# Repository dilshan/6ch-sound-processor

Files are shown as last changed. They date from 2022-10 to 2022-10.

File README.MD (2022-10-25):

# 5.1 channel analog audio processor

This project is a 5.1-channel, analog audio processor based on *PT2322* and [Arduino Nano](https://store.arduino.cc/products/arduino-nano).

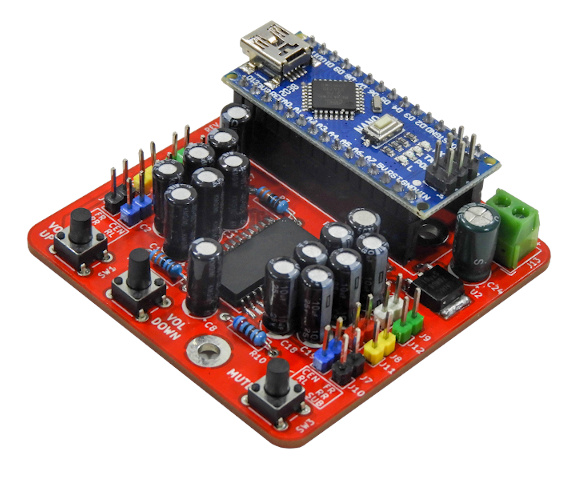
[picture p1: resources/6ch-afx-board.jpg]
Finished 5.1-channel analog audio processor board.


[*PT2322*](https://www.alldatasheet.com/datasheet-pdf/pdf/167269/ETC1/PT2322.html) is an inexpensive analog audio processor introduced by [*Princeton Technology Corporation*](http://www.princeton.com.tw/). It contains 6-channel individual channel attenuators, a 3-way tone control system for front-end speakers, and a 3D audio simulation system.

In this design, we combine *PT2322* with *Arduino Nano* and interface it with PC/embedded computing boards through a USB port. Native *GTK* UI application provides to control all functions of the *PT2322* IC.

This audio processing module is an open-source hardware project. All the design files, source codes, and compiled binaries are available in this repository.

- [6ch-sound-fx-arduino](https://github.com/dilshan/6ch-sound-processor/tree/main/6ch-sound-fx-arduino): Source code of the *Arduino Nano* firmware.
- [6ch-sound-fx-controller](https://github.com/dilshan/6ch-sound-processor/tree/main/6ch-sound-fx-controller): Source code of the sound processor control application.
- [kicad-design](https://github.com/dilshan/6ch-sound-processor/tree/main/kicad-design): *KiCAD* 6 schematic and PCB design.

## Assembling the module

The PCB of this module can directly order from the [PCBWay project page](https://www.pcbway.com/project/shareproject/5_1_channel_analog_audio_processor_231ad745.html). Also, the latest Gerber files of this module are available in the [release](https://github.com/dilshan/6ch-sound-processor/releases) section of this repository.

All the required components to assemble this module are in the BOM file at [here](https://github.com/dilshan/6ch-sound-processor/tree/main/kicad-design/6ch-sound-fx-proc-bom.pdf).

The entire assembly process of this module is shown in the below video:

5.1 Channel Audio Processor (https://youtu.be/wblaniLDYwU)

## Compiling source codes

*Arduino Nano* firmware of this project is written using [*PlatformIO*](https://platformio.org/). To compile and install the firmware, use the latest version of [*PlatformIO IDE*](https://platformio.org/platformio-ide).

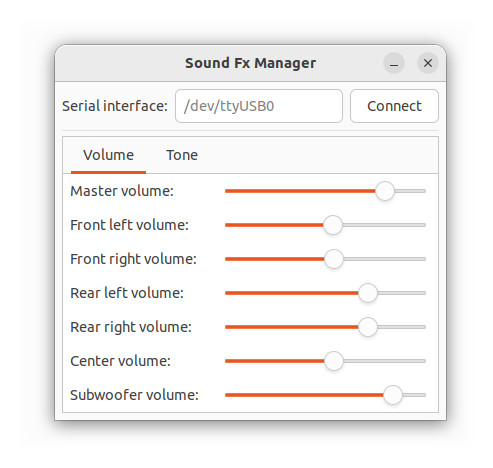
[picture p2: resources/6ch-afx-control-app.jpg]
Sound processor control application


The sound processor control application is a *GTK* application. *GTK* 3 development packages are required to compile this application. To compile the application, issue the `make` command from the source directory.

```
$ git clone git@github.com:dilshan/6ch-sound-processor.git
$ cd 6ch-sound-processor/6ch-sound-fx-controller/
$ make
```

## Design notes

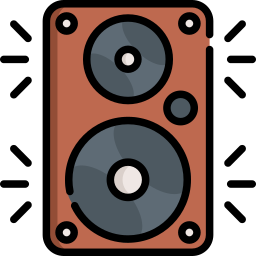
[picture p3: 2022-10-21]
6ch-sound-fx-controller/6ch-tone-control.png

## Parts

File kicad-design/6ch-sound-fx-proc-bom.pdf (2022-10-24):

6ch-sound-fx-proc

Reference(s) | Value | Footprint
A1 | Arduino Nano (V3) | Arduino Nano
| 10MFD / 16V | THT (Electrolytic capacitor)
C7,C9 | 0.0022MFD | SMD (0805)
C10,C11,C12,C13 | 0.01MFD | SMD (0805)
C14,C15,C16,C17,C26 | 0.1MFD | SMD (0805)
C24 | 100MFD / 16V | THT (Electrolytic capacitor)
C25 | 22MFD / 16V | THT (Electrolytic capacitor)
| 2.54mm 2-pin | 2.54mm, 2-pin male header
J13 | 2.54mm 2-pin | 2.54mm, 2-pin terminal block
Q1,Q2 | 2N7002 | SOT-23
| 100K | SMD (0805)
R7,R8 | 3.3K | THT (1% Metal film resistor)
R9,R10 | 6.2K | THT (1% Metal film resistor)
R17,R18,R19,R20 | 10K | SMD (0805)
R21 | 0R | SMD (0805)
SW1,SW2,SW3 | 6mm Tactile Switch
U1 | PT2322 | SSOP-28
U2 | LM78M08 | TO-252-2

C1,C2,C3,C4,C5,C6,C8,C18,C19,C 20,C21,C22,C23,C27

J1,J2,J3,J4,J5,J6,J7,J8,J9,J10,J11, J12

R1,R2,R3,R4,R5,R6,R11,R12,R13, R14,R15,R16

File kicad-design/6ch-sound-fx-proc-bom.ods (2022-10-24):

Reference(s) | Value | Footprint
A1 | Arduino Nano (V3) | Arduino Nano
C1,C2,C3,C4,C5,C6,C8,C18,C19,C20,C21,C22,C23,C27 | 10MFD / 16V | THT (Electrolytic capacitor)
C7,C9 | 0.0022MFD | SMD (0805)
C10,C11,C12,C13 | 0.01MFD | SMD (0805)
C14,C15,C16,C17,C26 | 0.1MFD | SMD (0805)
C24 | 100MFD / 16V | THT (Electrolytic capacitor)
C25 | 22MFD / 16V | THT (Electrolytic capacitor)
J1,J2,J3,J4,J5,J6,J7,J8,J9,J10,J11,J12 | 2.54mm 2-pin | 2.54mm, 2-pin male header
J13 | 2.54mm 2-pin | 2.54mm, 2-pin terminal block
Q1,Q2 | 2N7002 | SOT-23
R1,R2,R3,R4,R5,R6,R11,R12,R13,R14,R15,R16 | 100K | SMD (0805)
R7,R8 | 3.3K | THT (1% Metal film resistor)
R9,R10 | 6.2K | THT (1% Metal film resistor)
R17,R18,R19,R20 | 10K | SMD (0805)
R21 | 0R | SMD (0805)
SW1,SW2,SW3 | 6mm Tactile Switch
U1 | PT2322 | SSOP-28
U2 | LM78M08 | TO-252-2

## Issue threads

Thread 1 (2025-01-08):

hey no issue here but have a question about this project

Rick20230, 2025-01-08:
Hi im new to Arduino and esp32 stuff is there a way to have a wireless rf remote with 2 decoders one for 4 channels volume control and another decoder for 2 channels volume control i dont need any eq just need 4ch vol and 2 ch vol as separate volume controls would like to use this for car audio for front stereo rear stereo volume and subwoofer volume

Cheers Rick

btw sorry report idk how to message here hopfully its just a way to communicate to u and not a actual reporting to github

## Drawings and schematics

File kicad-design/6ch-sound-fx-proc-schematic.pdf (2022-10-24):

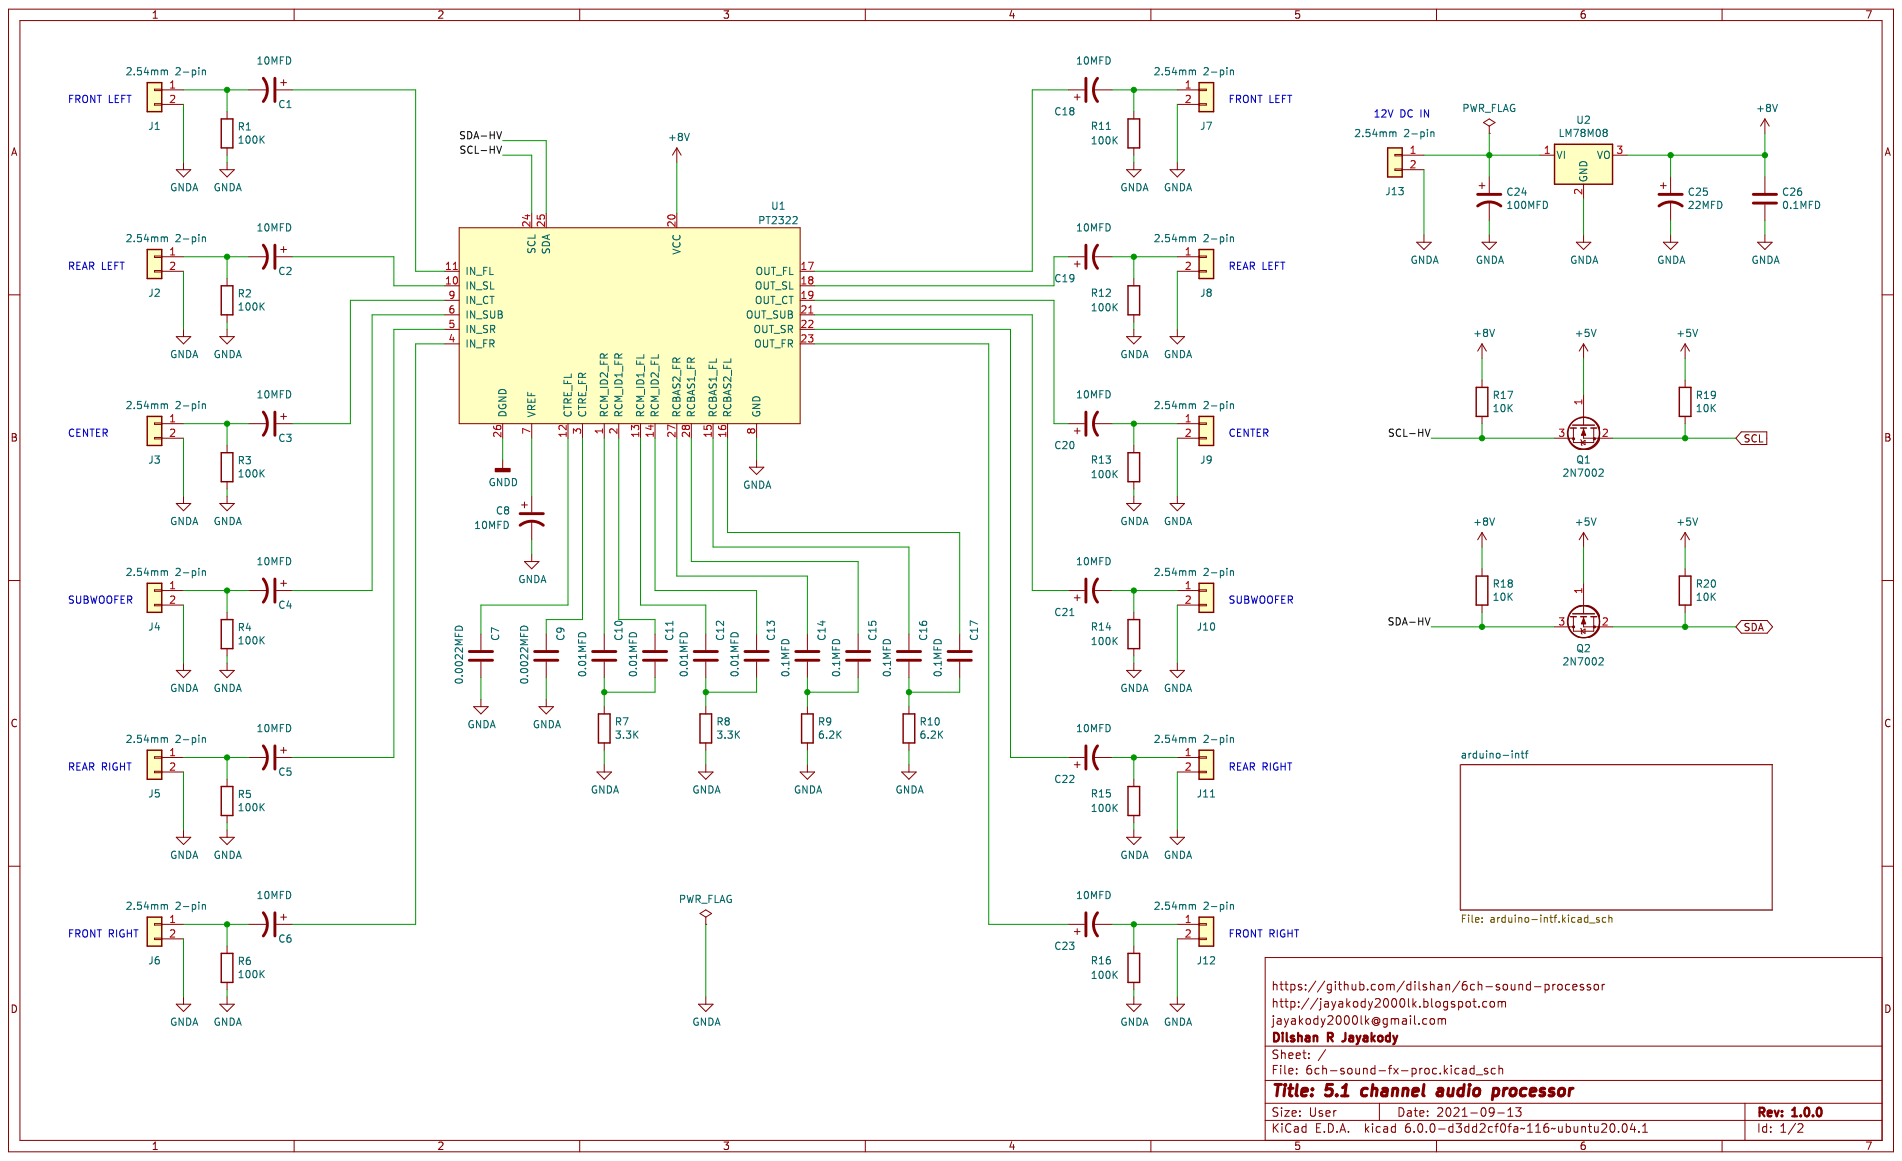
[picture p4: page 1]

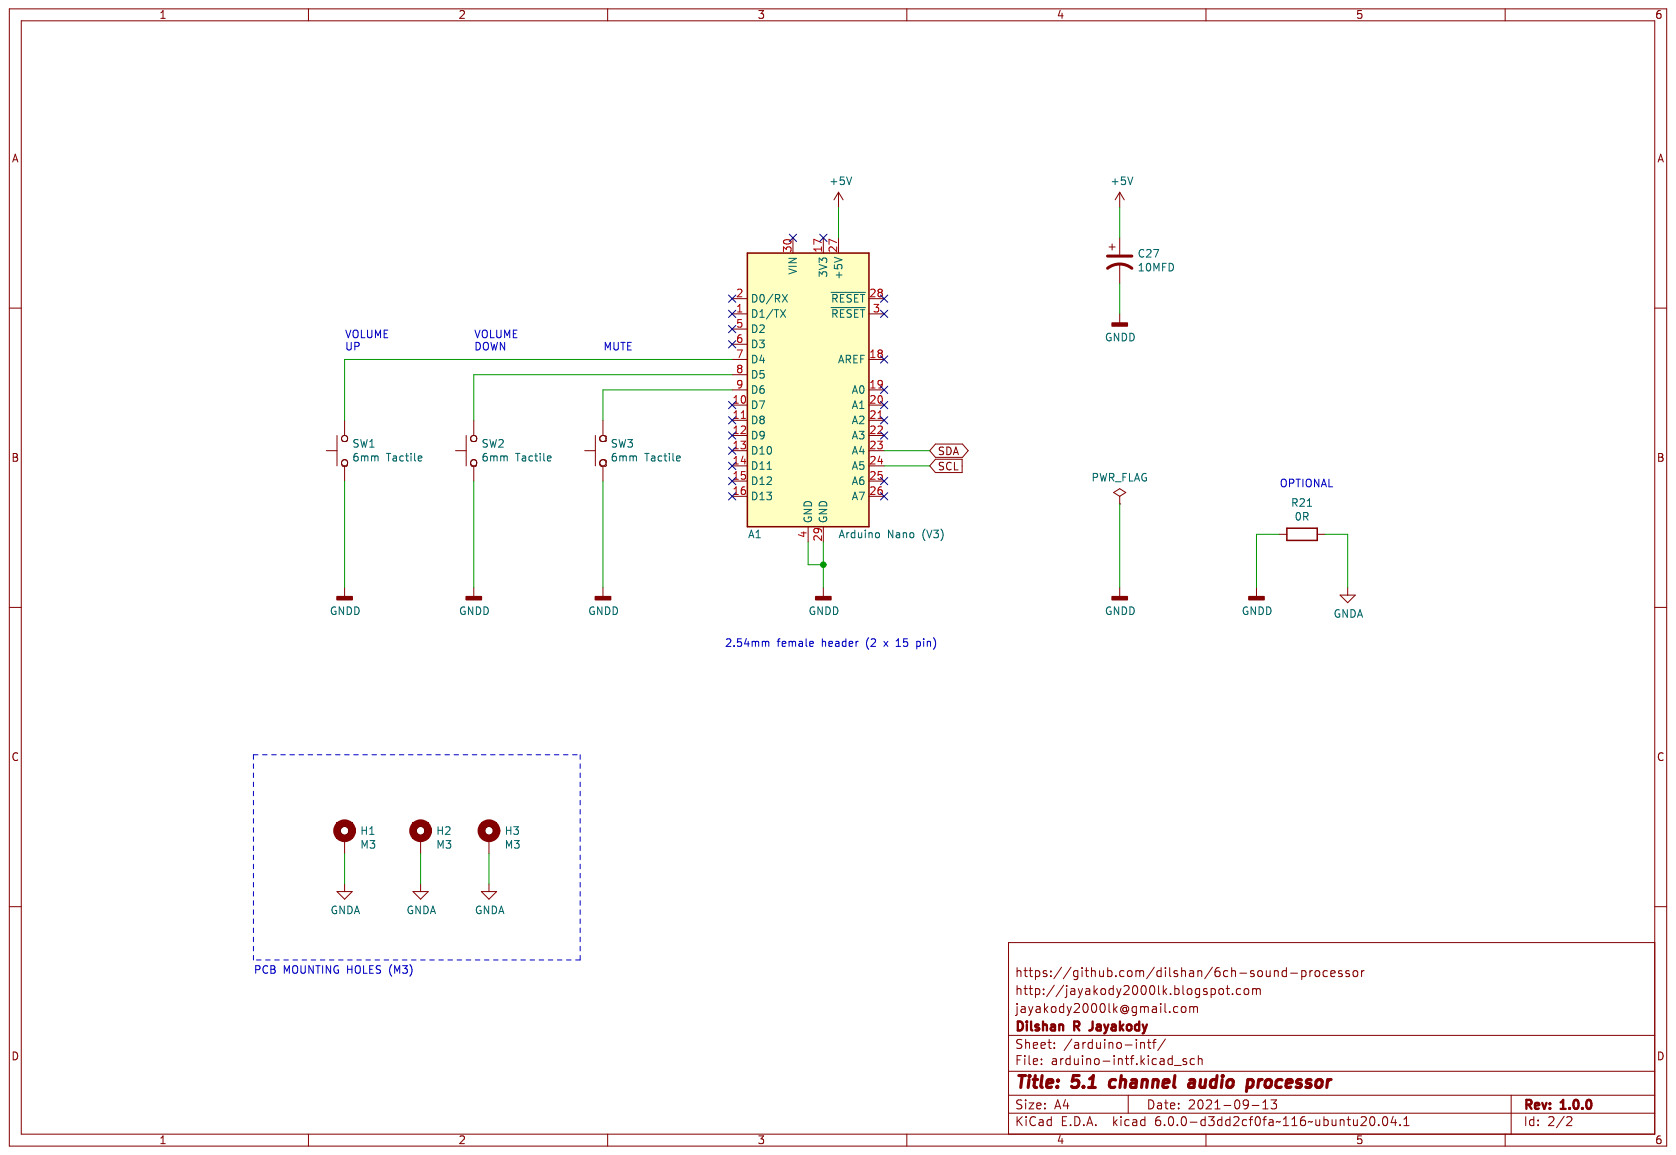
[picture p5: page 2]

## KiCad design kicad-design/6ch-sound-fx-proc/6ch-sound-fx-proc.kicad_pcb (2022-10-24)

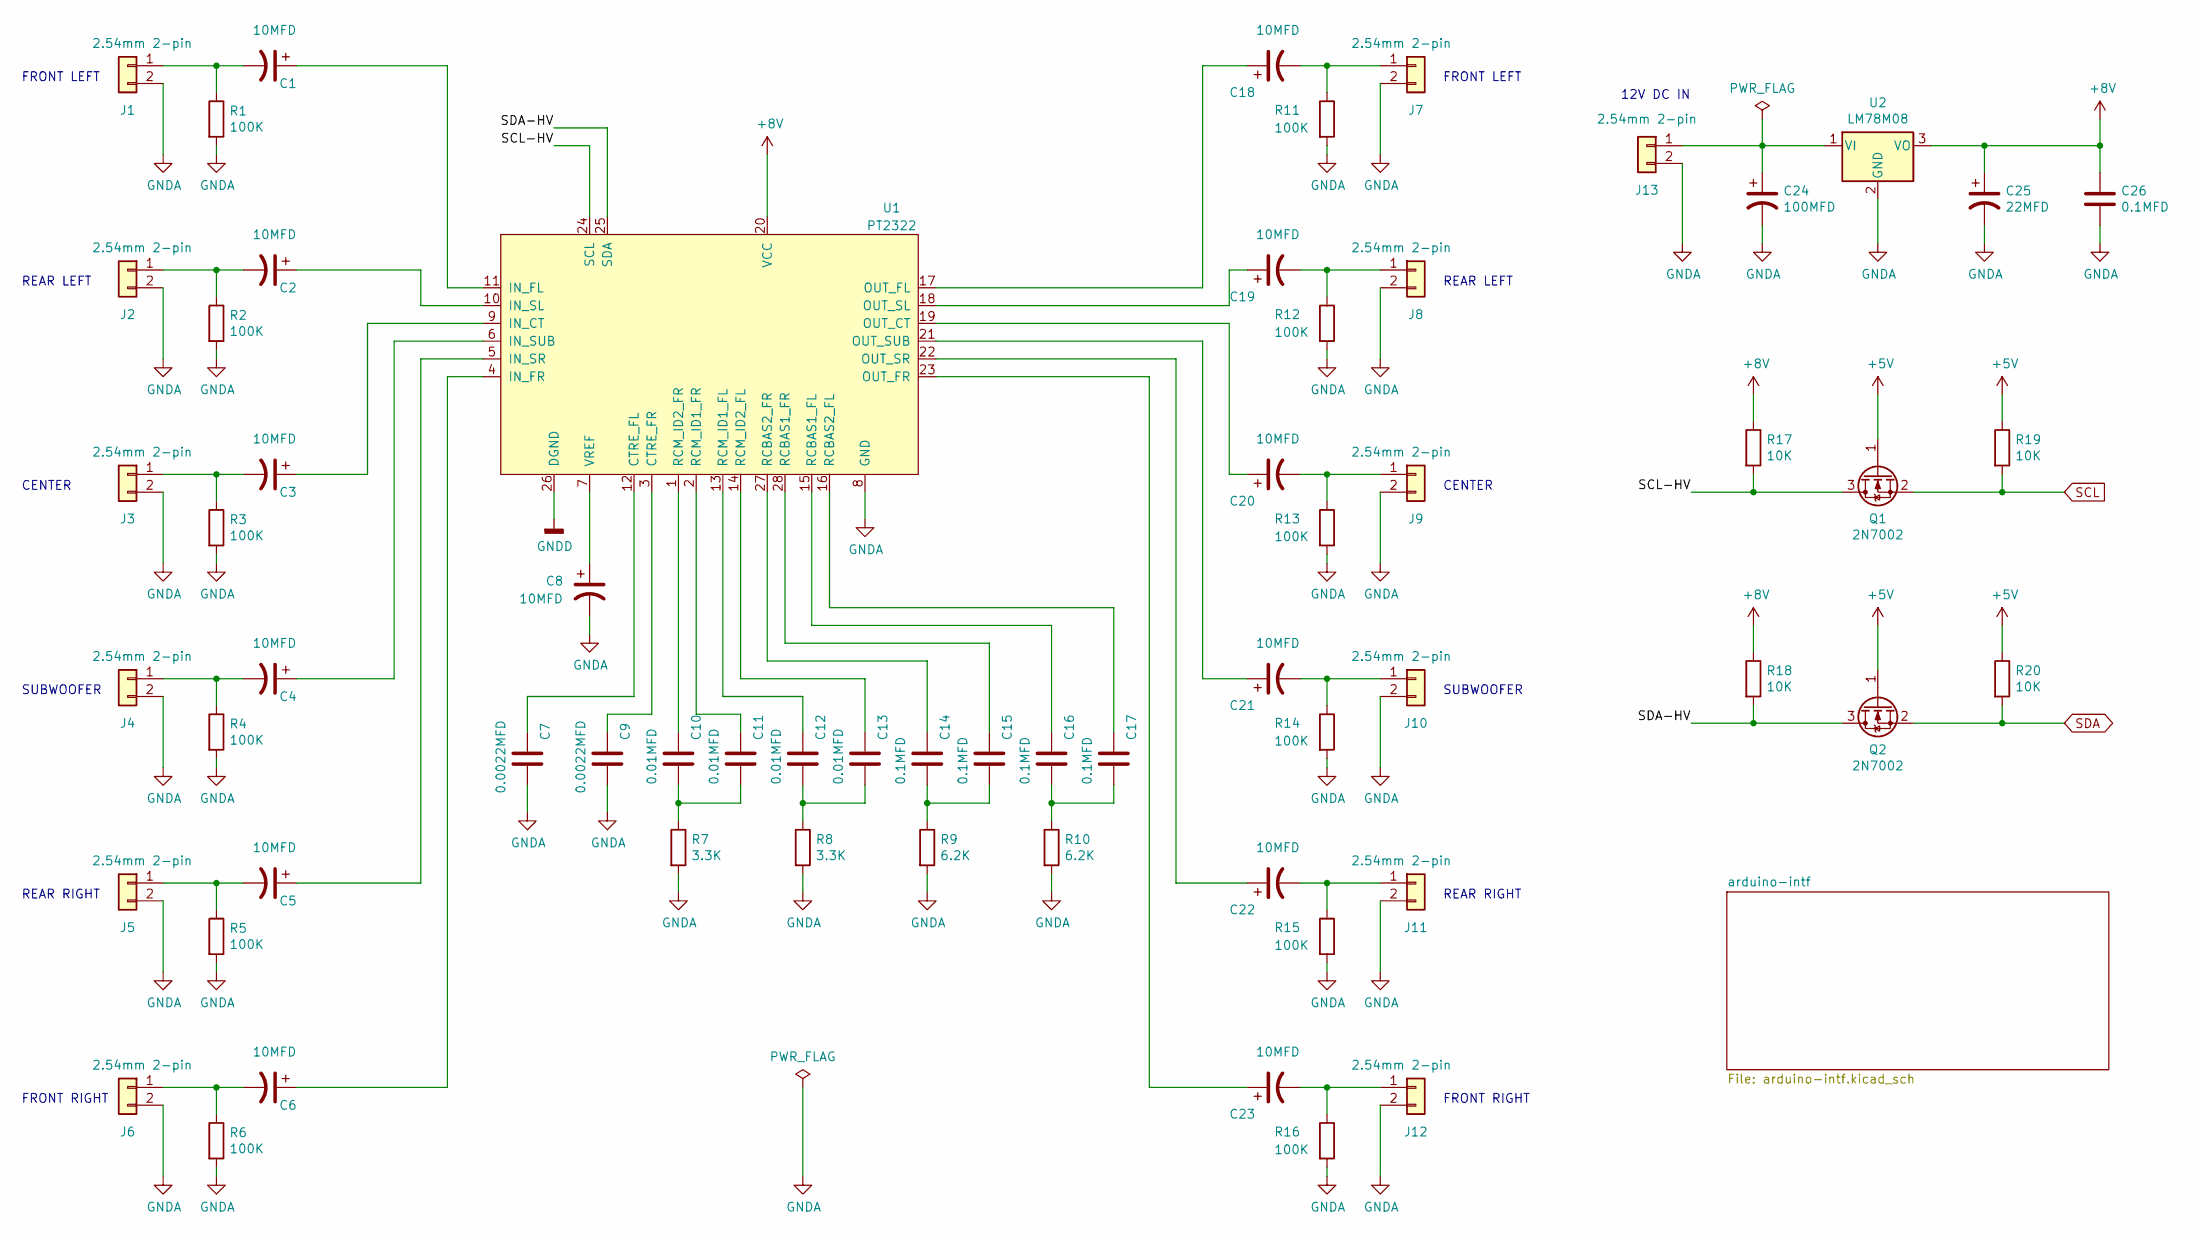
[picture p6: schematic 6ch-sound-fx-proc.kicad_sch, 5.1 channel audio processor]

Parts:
C1, C2, C3, C4, C5, C6, C8, C18, C19, C20, C21, C22, C23: 10MFD; CP_Radial_D5.0mm_P2.00mm
C7, C9: 0.0022MFD; C_0805_2012Metric_Pad1.18x1.45mm_HandSolder
C10, C11, C12, C13: 0.01MFD; C_0805_2012Metric_Pad1.18x1.45mm_HandSolder
C14, C15, C16, C17, C26: 0.1MFD; C_0805_2012Metric_Pad1.18x1.45mm_HandSolder
C24: 100MFD; CP_Radial_D6.3mm_P2.50mm
C25: 22MFD; CP_Radial_D5.0mm_P2.00mm
J1, J2, J3, J4, J5, J6, J7, J8, J9, J10, J11, J12: 2.54mm 2-pin; PinHeader_1x02_P2.54mm_Vertical
J13: 2.54mm 2-pin; PhoenixContact_MCV_1,5_2-G-3.5_1x02_P3.50mm_Vertical
Q1, Q2: 2N7002; SOT-23
R1, R2, R3, R4, R5, R6, R11, R12, R13, R14, R15, R16: 100K; R_0805_2012Metric_Pad1.20x1.40mm_HandSolder
R7, R8: 3.3K; R_Axial_DIN0207_L6.3mm_D2.5mm_P10.16mm_Horizontal
R9, R10: 6.2K; R_Axial_DIN0207_L6.3mm_D2.5mm_P10.16mm_Horizontal
R17, R18, R19, R20: 10K; R_0805_2012Metric_Pad1.20x1.40mm_HandSolder
U1: PT2322; SSOP-28_5.3x10.2mm_P0.65mm
U2: LM78M08; TO-252-2

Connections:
+5V: Q1.1 (G), Q2.1 (G), R19.1, R20.1; also elsewhere on the board
+8V: C25.1, C26.1, R17.1, R18.1, U1.20 (VCC), U2.3 (VO)
/SCL-HV: Q1.3 (D), R17.2, U1.24 (SCL)
/SDA-HV: Q2.3 (D), R18.2, U1.25 (SDA)
GNDA: C7.2, C8.2, C9.2, C24.2, C25.2, C26.2, J1.2, J2.2, J3.2, J4.2, J5.2, J6.2, J7.2, J8.2, J9.2, J10.2, J11.2, J12.2, J13.2, R1.2, R2.2, R3.2, R4.2, R5.2, R6.2, R7.2, R8.2, R9.2, R10.2, R11.2, R12.2, R13.2, R14.2, R15.2, R16.2, U1.8 (GND), U2.2 (GND); also elsewhere on the board
GNDD: U1.26 (DGND); also elsewhere on the board
unnamed: C1.1, U1.11 (IN_FL)
unnamed: C1.2, J1.1, R1.1
unnamed: C2.1, U1.10 (IN_SL)
unnamed: C2.2, J2.1, R2.1
unnamed: C3.1, U1.9 (IN_CT)
unnamed: C3.2, J3.1, R3.1
unnamed: C4.1, U1.6 (IN_SUB)
unnamed: C4.2, J4.1, R4.1
unnamed: C5.1, U1.5 (IN_SR)
unnamed: C5.2, J5.1, R5.1
unnamed: C6.1, U1.4 (IN_FR)
unnamed: C6.2, J6.1, R6.1
unnamed: C7.1, U1.12 (CTRE_FL)
unnamed: C8.1, U1.7 (VREF)
unnamed: C9.1, U1.3 (CTRE_FR)
unnamed: C10.1, U1.1 (RCM_ID2_FR)
unnamed: C10.2, C11.2, R7.1
unnamed: C11.1, U1.2 (RCM_ID1_FR)
unnamed: C12.1, U1.13 (RCM_ID1_FL)
unnamed: C12.2, C13.2, R8.1
unnamed: C13.1, U1.14 (RCM_ID2_FL)
unnamed: C14.1, U1.27 (RCBAS2_FR)
unnamed: C14.2, C15.2, R9.1
unnamed: C15.1, U1.28 (RCBAS1_FR)
unnamed: C16.1, U1.15 (RCBAS1_FL)
unnamed: C16.2, C17.2, R10.1
unnamed: C17.1, U1.16 (RCBAS2_FL)
unnamed: C18.1, U1.17 (OUT_FL)
unnamed: C18.2, J7.1, R11.1
unnamed: C19.1, U1.18 (OUT_SL)
unnamed: C19.2, J8.1, R12.1
unnamed: C20.1, U1.19 (OUT_CT)
unnamed: C20.2, J9.1, R13.1
unnamed: C21.1, U1.21 (OUT_SUB)
unnamed: C21.2, J10.1, R14.1
unnamed: C22.1, U1.22 (OUT_SR)
unnamed: C22.2, J11.1, R15.1
unnamed: C23.1, U1.23 (OUT_FR)
unnamed: C23.2, J12.1, R16.1
unnamed: C24.1, J13.1, U2.1 (VI)
SCL: Q1.2 (S), R19.2; also elsewhere on the board
SDA: Q2.2 (S), R20.2; also elsewhere on the board

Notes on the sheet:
SUBWOOFER
FRONT LEFT
FRONT RIGHT
REAR LEFT
REAR RIGHT
CENTER
12V DC IN

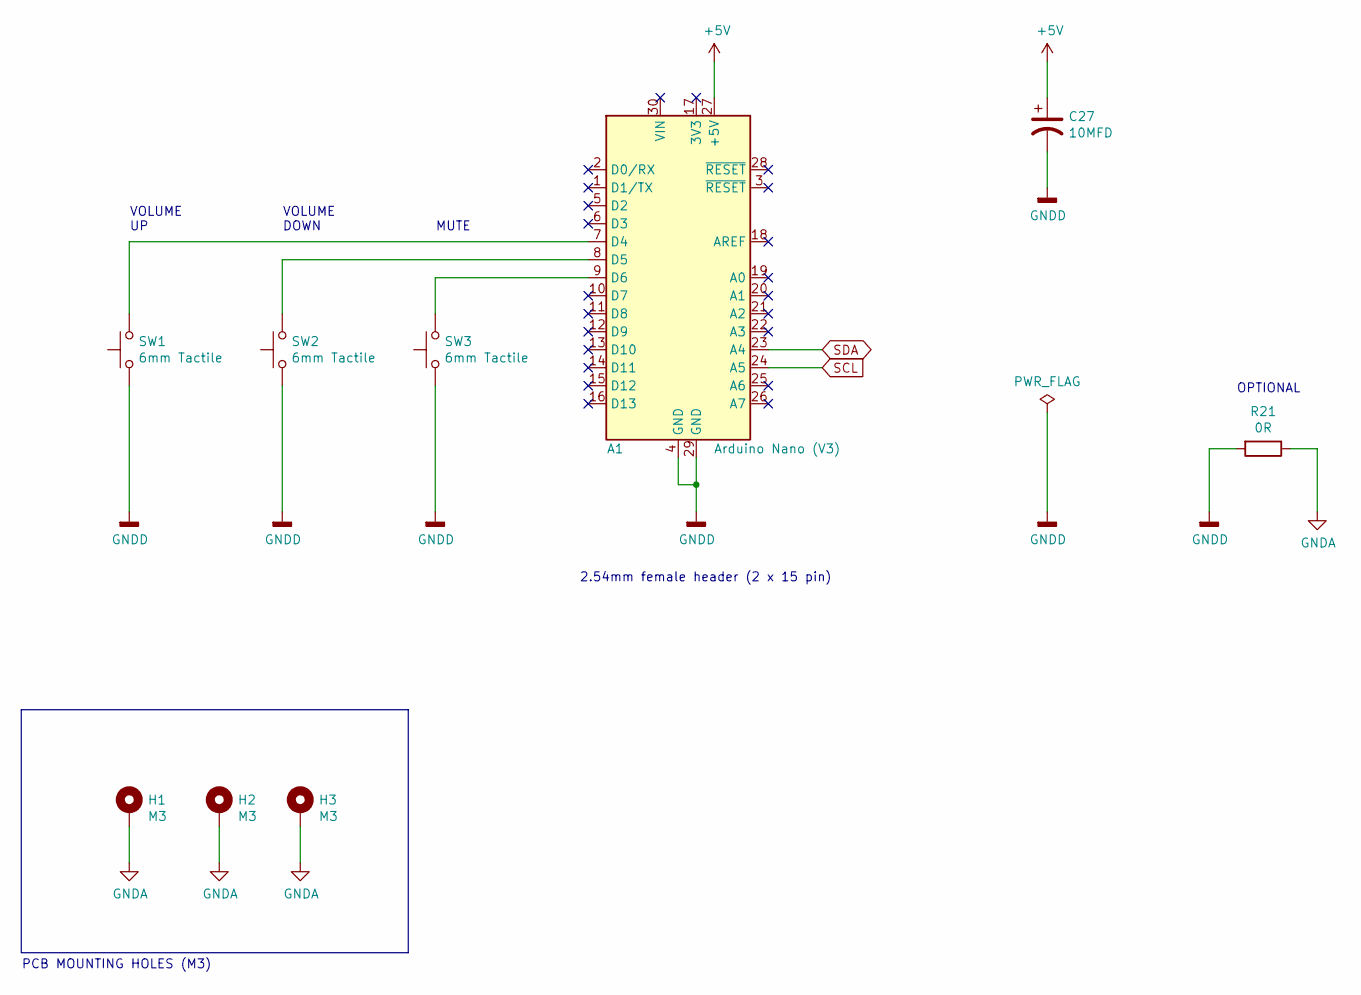
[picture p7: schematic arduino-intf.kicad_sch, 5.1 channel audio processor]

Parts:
A1: Arduino Nano (V3); Arduino_Nano
C27: 10MFD; CP_Radial_D5.0mm_P2.00mm
H1, H2, H3: M3; MountingHole_3.2mm_M3_Pad
R21: 0R; R_0805_2012Metric_Pad1.20x1.40mm_HandSolder
SW1, SW2, SW3: 6mm Tactile; SW_PUSH_6mm

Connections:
+5V: A1.27 (+5V), C27.1; also elsewhere on the board
GNDA: H1.1, H2.1, H3.1, R21.1; also elsewhere on the board
GNDD: A1.4 (GND), A1.29 (GND), C27.2, R21.2, SW1.1, SW2.1, SW3.1; also elsewhere on the board
unnamed: A1.7 (D4), SW1.2
unnamed: A1.8 (D5), SW2.2
unnamed: A1.9 (D6), SW3.2
SCL: A1.24 (A5); also elsewhere on the board
SDA: A1.23 (A4); also elsewhere on the board

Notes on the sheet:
2.54mm female header (2 x 15 pin)
VOLUME DOWN
PCB MOUNTING HOLES (M3)
VOLUME UP
OPTIONAL
MUTE

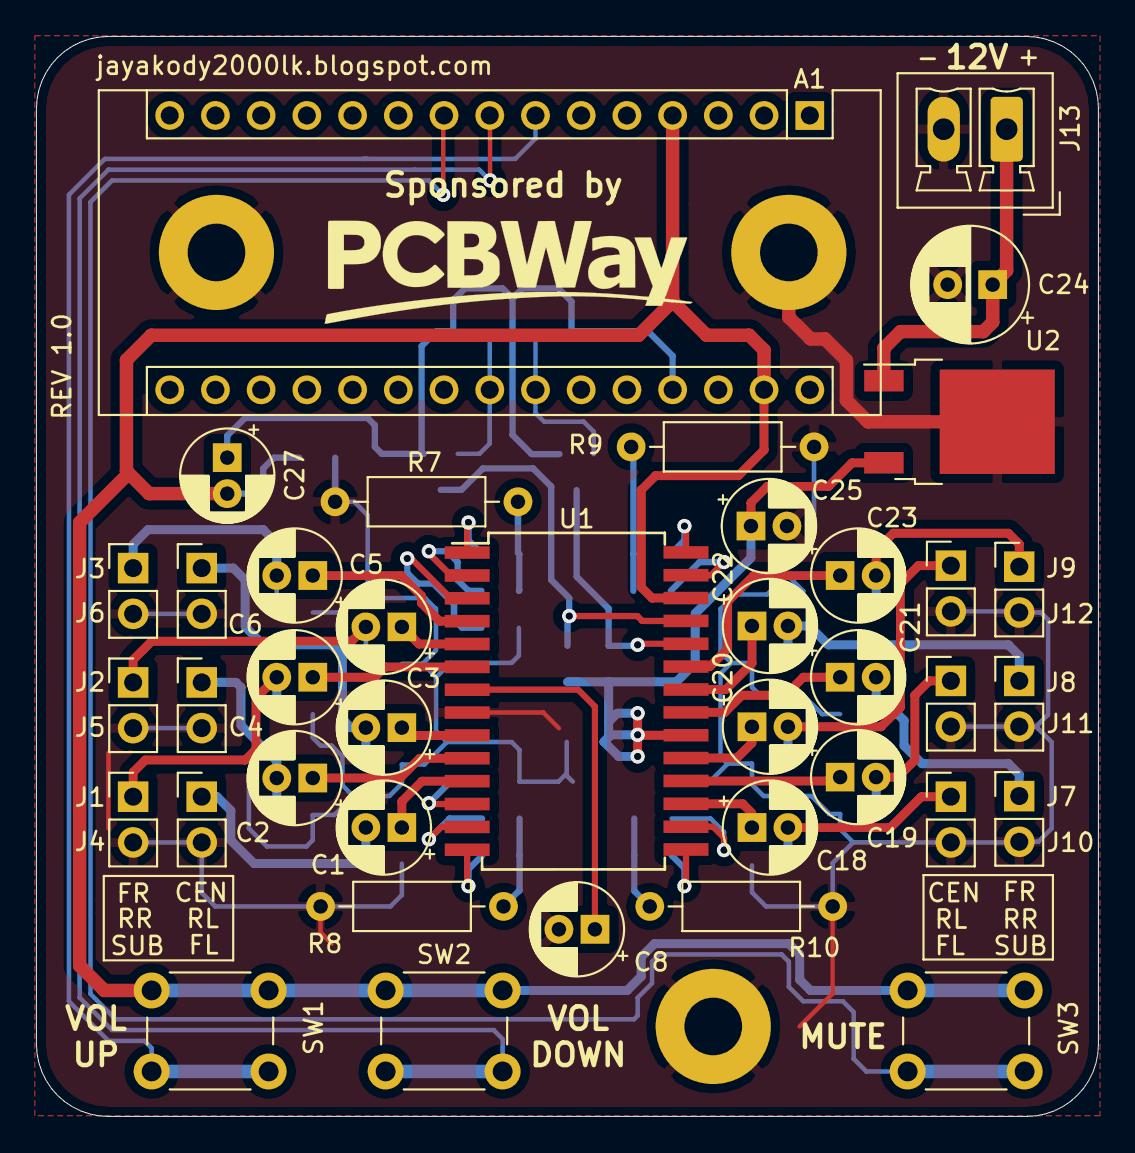
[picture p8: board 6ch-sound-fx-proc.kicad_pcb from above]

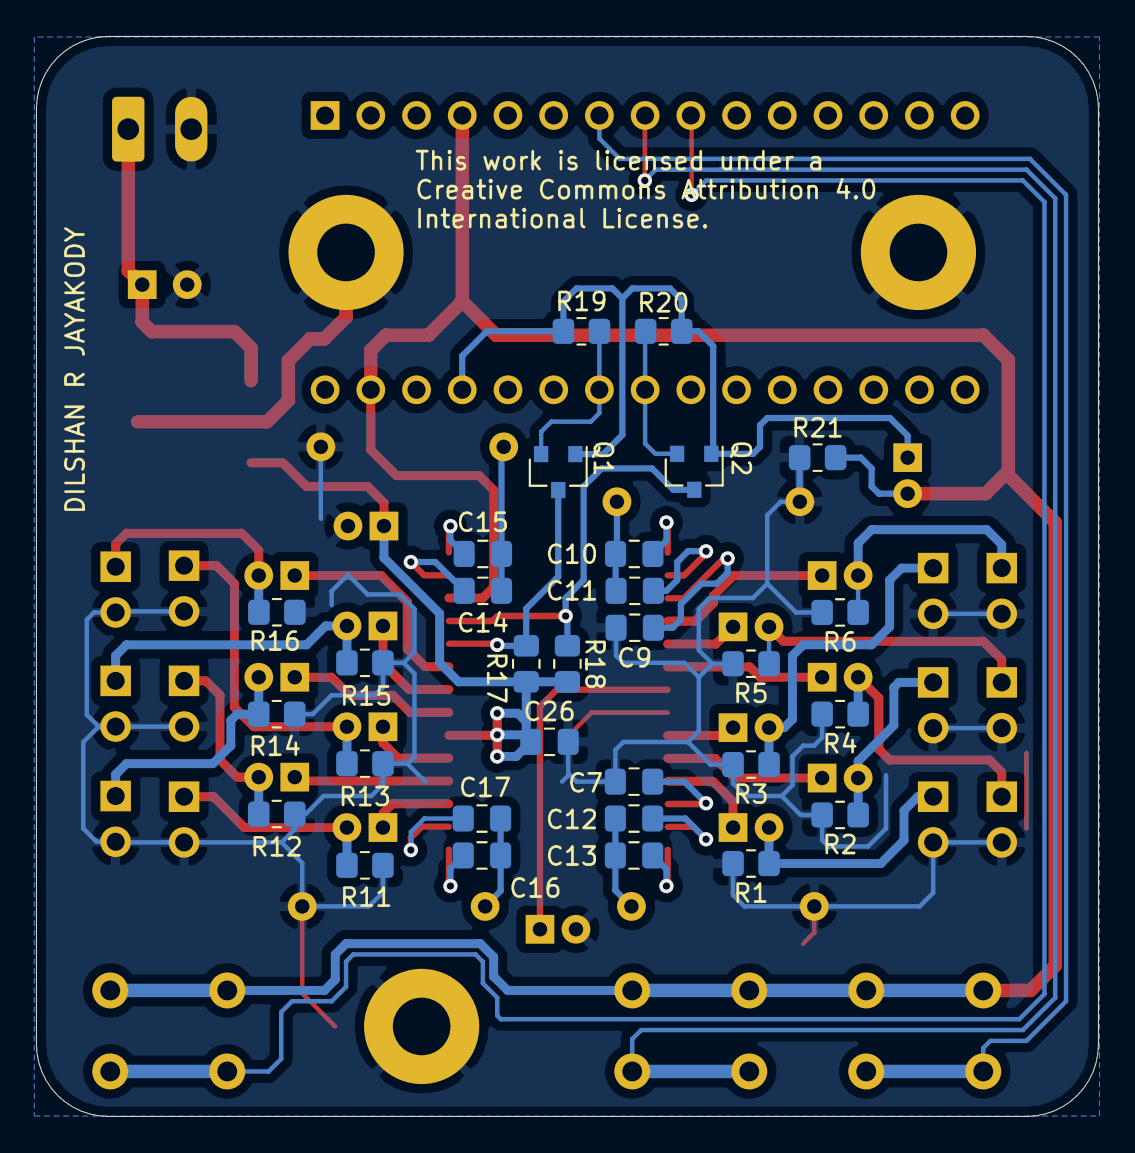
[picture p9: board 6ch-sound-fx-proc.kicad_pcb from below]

Board: 2 copper layers, 59.0 x 60.0 mm, 72 parts (30 on the bottom side), 51 nets.

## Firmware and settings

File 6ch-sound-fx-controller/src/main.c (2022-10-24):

//********************************************************************************
// Copyright (c) 2022 Dilshan R Jayakody.
// 6-channel sound processor - control panel.
//
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
#include <gtk/gtk.h>

#include "common.h"
#include "guidef.h"

#include "main.h"
#include "devcnt.h"
#include "pt2322.h"
#include "logger.h"

#include <stdio.h>
#include <unistd.h>
#include <fcntl.h>
#include <termios.h>
#include <errno.h>

audioSettings audioData;
commInfo commInfoData;

pthread_t controlThreadId;

#define GUI_CNT_MASTER_VOLUME   "scaleMasterVol"

#define GUI_CNT_TRIM_FRONT_LEFT     "scaleFLVolume"
#define GUI_CNT_TRIM_FRONT_RIGHT    "scaleFRVolume"
#define GUI_CNT_TRIM_REAR_LEFT      "scaleRLVolume"
#define GUI_CNT_TRIM_REAR_RIGHT     "scaleRRVolume"
#define GUI_CNT_TRIM_CENTER         "scaleCenVolume"
#define GUI_CNT_TRIM_SUBWOOFER      "scaleSubVolume"

#define GUI_CNT_TONE_BASS   "scaleBass"
#define GUI_CNT_TONT_TREBLE "scaleTreble"
#define GUI_CNT_TONE_MID    "scaleMid"

int main(int argc, char* argv [])
{
    GtkBuilder *builder; 
    GdkPixbuf *pixBuffer;

    printLogInfo("Starting application...");

    // Initialize common data structures.
    commInfoData.serialIntf = -1;
    commInfoData.audioControlData = &audioData;    
    commInfoData.masterVolumeEvent = masterVolumeChangedOnDev;
    commInfoData.trimChannelVolumeEvent = trimLevelChangedOnDev;
    commInfoData.toneLevelEvent = toneLevelChangedOnDev;
    commInfoData.effectEvent = effectChangedOnDev;

    // Initialize the GTK library.
    gtk_init(&argc, &argv);

    // Load main window from GLADE file and build the object.
    builder = gtk_builder_new_from_file("glade/6ch-sound-fx.glade");
    mainWindow.winMain = GTK_WIDGET(gtk_builder_get_object(builder, "appwinMain"));
    
    // Set window icon.
    pixBuffer = gdk_pixbuf_new_from_resource("/com/dilshan/6chafx/appicon", NULL);
    gtk_window_set_icon(GTK_WINDOW(mainWindow.winMain), pixBuffer);
    
    // Update control names to identify the common control events.
    gtk_widget_set_name(GTK_WIDGET(gtk_builder_get_object(builder, "scaleMasterVol")), GUI_CNT_MASTER_VOLUME);
    gtk_widget_set_name(GTK_WIDGET(gtk_builder_get_object(builder, "scaleFLVolume")), GUI_CNT_TRIM_FRONT_LEFT);
    gtk_widget_set_name(GTK_WIDGET(gtk_builder_get_object(builder, "scaleRLVolume")), GUI_CNT_TRIM_REAR_LEFT);
    gtk_widget_set_name(GTK_WIDGET(gtk_builder_get_object(builder, "scaleFRVolume")), GUI_CNT_TRIM_FRONT_RIGHT);
    gtk_widget_set_name(GTK_WIDGET(gtk_builder_get_object(builder, "scaleRRVolume")), GUI_CNT_TRIM_REAR_RIGHT);
    gtk_widget_set_name(GTK_WIDGET(gtk_builder_get_object(builder, "scaleCenVolume")), GUI_CNT_TRIM_CENTER);
    gtk_widget_set_name(GTK_WIDGET(gtk_builder_get_object(builder, "scaleSubVolume")), GUI_CNT_TRIM_SUBWOOFER);

    gtk_widget_set_name(GTK_WIDGET(gtk_builder_get_object(builder, "scaleBass")), GUI_CNT_TONE_BASS);
    gtk_widget_set_name(GTK_WIDGET(gtk_builder_get_object(builder, "scaleMid")), GUI_CNT_TONE_MID);
    gtk_widget_set_name(GTK_WIDGET(gtk_builder_get_object(builder, "scaleTreble")), GUI_CNT_TONT_TREBLE);

    mainWindow.txtSerialFile = GTK_ENTRY(gtk_builder_get_object(builder, "txtSerialFile"));
    mainWindow.btnConnect = GTK_BUTTON(gtk_builder_get_object(builder, "btnConnect"));
    mainWindow.adjMasterVolume = GTK_ADJUSTMENT(gtk_builder_get_object(builder, "adjTrimMaster"));

    mainWindow.trimFrontLeft = GTK_ADJUSTMENT(gtk_builder_get_object(builder, "adjTrimFL"));
    mainWindow.trimFrontRight = GTK_ADJUSTMENT(gtk_builder_get_object(builder, "adjTrimFR"));
    mainWindow.trimRearLeft = GTK_ADJUSTMENT(gtk_builder_get_object(builder, "adjTrimRL"));
    mainWindow.trimRearRight = GTK_ADJUSTMENT(gtk_builder_get_object(builder, "adjTrimRR"));
    mainWindow.trimCenter = GTK_ADJUSTMENT(gtk_builder_get_object(builder, "adjTrimCenter"));
    mainWindow.trimSubwoofer = GTK_ADJUSTMENT(gtk_builder_get_object(builder, "adjTrimSub")); 

    mainWindow.toneBass = GTK_ADJUSTMENT(gtk_builder_get_object(builder, "adjBass"));
    mainWindow.toneMid = GTK_ADJUSTMENT(gtk_builder_get_object(builder, "adjMid"));
    mainWindow.toneTreble = GTK_ADJUSTMENT(gtk_builder_get_object(builder, "adjTreble"));

    mainWindow.effect3D = GTK_CHECK_BUTTON(gtk_builder_get_object(builder, "chk3d"));
    mainWindow.effectTone = GTK_CHECK_BUTTON(gtk_builder_get_object(builder, "chkTone"));

    mainWindow.grdVolume = GTK_WIDGET(gtk_builder_get_object(builder, "grdVolume"));
    mainWindow.grdTone = GTK_WIDGET(gtk_builder_get_object(builder, "grdTone"));

    gtk_builder_connect_signals(builder, NULL);

    // Release builder.
    g_object_unref(builder);

    printLogInfo("Finish loading all window objects");

    // Set main window properties.
    gtk_window_set_title(GTK_WINDOW(mainWindow.winMain), "Sound Fx Manager");

    // Set default UI behaviours.
    gtk_entry_set_placeholder_text(mainWindow.txtSerialFile, "/dev/ttyUSB0");
    
    // Show main application window.
    gtk_widget_show(mainWindow.winMain);  
    gtk_main();

    return 0;
}

void on_appwinMain_destroy()
{
    // Close open serial session.
    if(commInfoData.serialIntf > -1)
    {
        printLogInfo("Closing the serial session");

        close(commInfoData.serialIntf);
        commInfoData.serialIntf = -1;
    }
    
    // Terminate application.    
    gtk_main_quit();
}

void on_adjTrimMaster_value_changed(GtkAdjustment* self, gpointer user_data)
{
    audioData.master = PT2322_MASTER_VOLUME_MIN - (gtk_adjustment_get_value(self));
}

void on_chkTone_toggled(GtkToggleButton *togglebutton, gpointer user_data)
{
    audioData.isToneDisable = !gtk_toggle_button_get_active(GTK_TOGGLE_BUTTON(togglebutton));
}

void on_chk3d_toggled(GtkToggleButton *togglebutton, gpointer user_data)
{
    audioData.is3DDisable = !gtk_toggle_button_get_active(GTK_TOGGLE_BUTTON(togglebutton));
}

void on_adjTrimSubChannel_value_changed(GtkAdjustment* self, gpointer user_data)
{
    const gchar *adjControl = gtk_widget_get_name(GTK_WIDGET(user_data));
    unsigned char adjValue = PT2322_TRIM_MIN - (gtk_adjustment_get_value(self));

    if(strcmp(adjControl, GUI_CNT_TRIM_FRONT_LEFT) == 0)
    {
        audioData.trimSettings.frontLeft = adjValue;
    }
    else if(strcmp(adjControl, GUI_CNT_TRIM_FRONT_RIGHT) == 0)
    {
        audioData.trimSettings.frontRight = adjValue;
    }
    else if(strcmp(adjControl, GUI_CNT_TRIM_REAR_LEFT) == 0)
    {
        audioData.trimSettings.rearLeft = adjValue;
    }
    else if(strcmp(adjControl, GUI_CNT_TRIM_REAR_RIGHT) == 0)
    {
        audioData.trimSettings.rearRight = adjValue;
    }
    else if(strcmp(adjControl, GUI_CNT_TRIM_CENTER) == 0)
    {
        audioData.trimSettings.center = adjValue;
    }
    else if(strcmp(adjControl, GUI_CNT_TRIM_SUBWOOFER) == 0)
    {
        audioData.trimSettings.subwoofer = adjValue;
    }
    else
    {
        // This block should not reachable!
        printLogError("Unknown trim control ID.");
    }
}

void on_adjTone_value_changed(GtkAdjustment* self, gpointer user_data)
{
    const gchar *adjControl = gtk_widget_get_name(GTK_WIDGET(user_data));
    unsigned char adjValue = gtk_adjustment_get_value(self);

    if(strcmp(adjControl, GUI_CNT_TONE_BASS) == 0)
    {
        audioData.toneSettings.bass = adjValue;
    }
    else if(strcmp(adjControl, GUI_CNT_TONT_TREBLE) == 0)
    {
        audioData.toneSettings.treble = adjValue;
    }
    else if(strcmp(adjControl, GUI_CNT_TONE_MID) == 0)
    {
        audioData.toneSettings.mid = adjValue;
    }
    else
    {
        // This block should not reachable!
        printLogError("Unknown tone control ID.");
    }
}

void on_btnConnect_pressed(GtkButton *button, gpointer user_data)
{    
    // Extracting and validating serial interface path.
    int threadStatus;
    const gchar* serialPortPath;
    GtkWidget* msgDlg;

    gtk_widget_set_sensitive(GTK_WIDGET(button), FALSE);
    gtk_widget_set_sensitive(GTK_WIDGET(mainWindow.txtSerialFile), FALSE);
    gtk_editable_set_editable(GTK_EDITABLE(mainWindow.txtSerialFile), FALSE);

    serialPortPath = gtk_entry_get_text(GTK_ENTRY(mainWindow.txtSerialFile));
    if(serialPortPath != NULL)
    {
        if(strlen(serialPortPath) > 0)
        {
            // Check the availability of the file and its permissions.
            if(access(serialPortPath, (R_OK | W_OK | F_OK)) == 0)
            {
                commInfoData.serialIntf = createSerialSession(serialPortPath);
                if(commInfoData.serialIntf == -1)
                {
                    // Unable to create serial session on the given path.
                    msgDlg = gtk_message_dialog_new(GTK_WINDOW(mainWindow.winMain), GTK_DIALOG_DESTROY_WITH_PARENT, GTK_MESSAGE_ERROR, GTK_BUTTONS_OK, "Unable to create serial session");
                    gtk_dialog_run(GTK_DIALOG(msgDlg));
                    gtk_widget_destroy(msgDlg);
                }

                // Checking for valid device by sending a ping request to the device!
                if(isValidDevice(&commInfoData))
                {
                    printLogInfo("Create serial session successfully");

                    // Create control thread to transfer settings to the device.                
                    threadStatus = pthread_create(&controlThreadId, NULL, &controlThreadHandler, &commInfoData);
                    if(threadStatus)
                    {
                        // Unable to create control thread.
                        printLogError("Unable to create control thread");

                        msgDlg = gtk_message_dialog_new(GTK_WINDOW(mainWindow.winMain), GTK_DIALOG_DESTROY_WITH_PARENT, GTK_MESSAGE_ERROR, GTK_BUTTONS_OK, "Unable to create control thread.\n\n%s", g_strerror(errno));
                        gtk_dialog_run(GTK_DIALOG(msgDlg));
                        gtk_widget_destroy(msgDlg);
                    }

                    // Enable tone and volume grids for user input.
                    gtk_widget_set_sensitive(mainWindow.grdVolume, TRUE);
                    gtk_widget_set_sensitive(mainWindow.grdTone, TRUE);

                    // Successfully establish a link with the device.
                    return;
                }
                else
                {
                    // The device attached to the port is not responding or invalid.
                    msgDlg = gtk_message_dialog_new(GTK_WINDOW(mainWindow.winMain), GTK_DIALOG_DESTROY_WITH_PARENT, GTK_MESSAGE_WARNING, GTK_BUTTONS_OK, "Device is not responding or unidentified device.");
                    gtk_dialog_run(GTK_DIALOG(msgDlg));
                    gtk_widget_destroy(msgDlg);
                }
            }
            else
            {
                // Unable to find the specified file or required permission are not available.
                msgDlg = gtk_message_dialog_new(GTK_WINDOW(mainWindow.winMain), GTK_DIALOG_DESTROY_WITH_PARENT, GTK_MESSAGE_ERROR, GTK_BUTTONS_OK, "Unable to open the specified serial interface.\n\n%s", g_strerror(errno));
                gtk_dialog_run(GTK_DIALOG(msgDlg));
                gtk_widget_destroy(msgDlg);
            }
        }
        else
        {
            // Serial interface path is not specified by the user.
            msgDlg = gtk_message_dialog_new(GTK_WINDOW(mainWindow.winMain), GTK_DIALOG_DESTROY_WITH_PARENT, GTK_MESSAGE_WARNING, GTK_BUTTONS_OK, "Serial interface path is not specified.");
            gtk_dialog_run(GTK_DIALOG(msgDlg));
            gtk_widget_destroy(msgDlg);

            // Set focus to the required field.
            gtk_widget_grab_focus(GTK_WIDGET(mainWindow.txtSerialFile));
        }
    }

    // Reactivate input controls.
    gtk_widget_set_sensitive(GTK_WIDGET(button), TRUE);
    gtk_widget_set_sensitive(GTK_WIDGET(mainWindow.txtSerialFile), TRUE);
    gtk_editable_set_editable(GTK_EDITABLE(mainWindow.txtSerialFile), TRUE);
}

void on_txtSerialFile_activate(GtkEntry *entry, gpointer  user_data)
{
    on_btnConnect_pressed(mainWindow.btnConnect, user_data);
}

void masterVolumeChangedOnDev(unsigned char newLevel)
{
    audioData.master = newLevel;
    gtk_adjustment_set_value(mainWindow.adjMasterVolume, (PT2322_MASTER_VOLUME_MIN - newLevel));
}

void trimLevelChangedOnDev(enum ControlID cID, unsigned char newLevel)
{    
    GtkAdjustment *adjControl = NULL;

    switch(cID)
    {
        case CID_TRIM_FRONT_LEFT:
            adjControl = mainWindow.trimFrontLeft;
            break;
        case CID_TRIM_FRONT_RIGHT:
            adjControl = mainWindow.trimFrontRight;
            break;
        case CID_TRIM_REAR_LEFT:
            adjControl = mainWindow.trimRearLeft;
            break;
        case CID_TRIM_REAR_RIGHT:
            adjControl = mainWindow.trimRearRight;
            break;
        case CID_CENTER:
            adjControl = mainWindow.trimCenter;
            break;
        case CID_SUBWOOFER:
            adjControl = mainWindow.trimSubwoofer;
            break;
        default:
            ;
    }

    if(adjControl != NULL)
    {
        gtk_adjustment_set_value(adjControl, (PT2322_TRIM_MIN - newLevel));
    }
}

void toneLevelChangedOnDev(enum ControlID cID, unsigned char newLevel)
{
    GtkAdjustment *adjControl = NULL;

    switch(cID)
    {
        case CID_BASS:
            adjControl = mainWindow.toneBass;
            break;
        case CID_MID:
            adjControl = mainWindow.toneMid;
            break;
        case CID_TREBLE:
            adjControl = mainWindow.toneTreble;
            break;
        default:
            ;
    }

    if(adjControl != NULL)
    {
        gtk_adjustment_set_value(adjControl, newLevel);
    }
}

void effectChangedOnDev(enum ControlID cID, gboolean newState)
{
    GtkCheckButton *chkControl = NULL;

    if(cID == CID_3DFX)
    {
        chkControl = mainWindow.effect3D;
    }
    else if(cID == CID_TONE)
    {
        chkControl = mainWindow.effectTone;
    }

    if(chkControl != NULL)
    {
        gtk_toggle_button_set_active(GTK_TOGGLE_BUTTON(chkControl), !newState);
    }
}

gboolean isValidDevice(commInfo *comIntf)
{
    unsigned char tryCount = 0;
    char pingReq[7], regStatus[4] = {[0 ... 3] = 0};
    ssize_t status;

    if(comIntf != NULL)
    {
        sprintf(pingReq, "%s", PING_CMD_DEV_ID);
                
        // Try to identify the target device by sending the ping command multipal times.
        while (tryCount < DEV_ID_TRY_COUNT)
        {
            // Send ping command to the specified serial port/device.
            status = write(comIntf->serialIntf, pingReq, sizeof(pingReq));
            usleep(50);

            if(status >= sizeof(pingReq))
            {                
                status = read(comIntf->serialIntf, regStatus, 3);
                if(status > 0)
                {
                    regStatus[3] = 0;

                    // Check for successful reponse from the device.
                    if(strcmp(regStatus, CNT_ACK) == 0)
                    {                    
                        printLogInfo("Got successful response from the device");
                        return TRUE;
                    }
                }

                printLogInfo("Device ping command fail with error");
            }
            else
            {
                // Allow sometime to respond the device on the serial port.
                usleep(100);
            }

            tryCount++;
        }
    }

    // Device not found on the specified serial port!
    return FALSE;
}

int createSerialSession(const char *serialPath)
{
    int result;
    struct termios ttySession;

    result= open(serialPath, O_RDWR);

    // Get existing terminal attributes.
    if(tcgetattr(result, &ttySession) != 0)
    {
        // Unable to read existing terminal attributes.
        printLogError("Unable to read terminal attributes");
        return -1;
    }

    // Set serial session with no parity bit, one stop bit and without hardware flow control.
    ttySession.c_cflag = ttySession.c_cflag & (~(PARENB | CSTOPB | CSIZE | CRTSCTS));

    // Set 8-bits per byte, enable read and not to check carrier signal.
    ttySession.c_cflag = ttySession.c_cflag | (CS8 | CREAD | CLOCAL);

    // Turn off canonical mode, echo, new-line echo, erasure.
    ttySession.c_lflag = ttySession.c_lflag & (~(ICANON | ECHO | ECHOE | ECHONL | ISIG));

    // Disable software flow control and handling the receiving byte stream.
    ttySession.c_iflag = ttySession.c_iflag & (~(IXON | IXOFF | IXANY | IGNBRK | BRKINT | PARMRK | ISTRIP | INLCR | IGNCR | ICRNL ));

    // Disable converting newline to carriage return/line feed and handling the outgoing byte stream.
    ttySession.c_oflag = ttySession.c_oflag & (~(OPOST | ONLCR));

    // Wait time configuration. 
    // http://unixwiz.net/techtips/termios-vmin-vtime.html
    ttySession.c_cc[VTIME] = 5;
    ttySession.c_cc[VMIN] = 0;

    // Set I/O baud rates.
    cfsetispeed(&ttySession, B38400);
    cfsetospeed(&ttySession, B38400);

    // Set new terminal attributes.
    if (tcsetattr(result, TCSANOW, &ttySession) != 0)
    {
        // Unable to set new terminal attributes.
        printLogError("Unable to set terminal attributes");
        return -1;
    }

    // Flush the content in serial buffer.
    usleep(20000);
    tcflush(result, TCIOFLUSH);

    return result;
}

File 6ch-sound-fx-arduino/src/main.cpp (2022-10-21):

//********************************************************************************
// Copyright (c) 2022 Dilshan R Jayakody.
// 6-channel sound processor - Arduino Nano firmware.
//
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
#include <Arduino.h>
#include <Wire.h>
#include <EEPROM.h>

#include "pt2322.h"
#include "confmem.h"

#include "config.h"
#include "common.h"

audioSettings audioConfig;
unsigned char lastVolUp, lastVolDown, lastMute;
unsigned char autoInc, autoDec;
unsigned long pressDelay;

void updateTrimLevels(trimLevel *trimConf)
{
    setTrimLevel(PT2322_TRIM_CHANNEL_REAR_LEFT, trimConf->rearLeft);
    setTrimLevel(PT2322_TRIM_CHANNEL_REAR_RIGHT, trimConf->rearRight);
    setTrimLevel(PT2322_TRIM_CHANNEL_FRONT_LEFT, trimConf->frontLeft);
    setTrimLevel(PT2322_TRIM_CHANNEL_FRONT_RIGHT, trimConf->frontRight);
    setTrimLevel(PT2322_TRIM_CHANNEL_CENTER, trimConf->center);
    setTrimLevel(PT2322_TRIM_CHANNEL_SUBWOOFER, trimConf->subwoofer);
}

void updateToneLevels(toneLevel *toneConf)
{
    setToneLevel(PT2322_TONE_BASS, toneConf->bass);
    setToneLevel(PT2322_TONE_TREBLE, toneConf->treble);
    setToneLevel(PT2322_TONE_MID, toneConf->mid);
}

void sendControlValue(const char *cmdID, unsigned char value)
{
    char buffer[6];
    
    // Copy command ID to the response.
    buffer[0] = cmdID[0];
    buffer[1] = cmdID[1];
    buffer[2] = cmdID[2];

    // Copy value to the response.
    buffer[4] = ((value % 10) + 0x30);
    buffer[3] = ((value / 10) + 0x30);

    buffer[5] = 0;

    Serial.print(buffer);     
}

void setup() 
{
    // Initialize USART0 interface to communicate with PC.
    Serial.begin(SERIAL_COMM_BAUD_RATE);
    Serial.setTimeout(SERIAL_TIMEOUT_MS);

    // Initialize I2C interface to communicate with PT2322.
    Wire.begin();

    // Set input pin configuration for VOL+, VOL- and MUTE buttons.
    pinMode(PIN_VOL_UP, INPUT_PULLUP);
    pinMode(PIN_VOL_DOWN, INPUT_PULLUP);
    pinMode(PIN_MUTE, INPUT_PULLUP);

    // Initialize PT2322.
    delay(500);
    initPT2322();

    // Update configuration to defaults.
    audioConfig.trimSettings.frontLeft = PT2322_TRIM_MAX;
    audioConfig.trimSettings.frontRight = PT2322_TRIM_MAX;
    audioConfig.trimSettings.rearLeft = PT2322_TRIM_MAX;
    audioConfig.trimSettings.rearRight = PT2322_TRIM_MAX;
    audioConfig.trimSettings.center = PT2322_TRIM_MAX;
    audioConfig.trimSettings.subwoofer = PT2322_TRIM_MAX;

    audioConfig.toneSettings.bass = PT2322_TONE_MIN;
    audioConfig.toneSettings.treble = PT2322_TONE_MIN;
    audioConfig.toneSettings.mid = PT2322_TONE_MIN;

    audioConfig.isMute = FALSE;
    audioConfig.is3DDisable = FALSE;
    audioConfig.isToneDisable = FALSE;
    
    audioConfig.master = PT2322_MASTER_VOLUME_MIN;

    // Try to restore last user setting into the configuration structure.
    getConfigValue(EEPROM_ADDR_MASTER_VOLUME, &(audioConfig.master));

    getConfigValue(EEPROM_ADDR_TRIM_FRONT_LEFT, &(audioConfig.trimSettings.frontLeft));
    getConfigValue(EEPROM_ADDR_TRIM_FRONT_RIGHT, &(audioConfig.trimSettings.frontRight));
    getConfigValue(EEPROM_ADDR_TRIM_REAR_LEFT, &(audioConfig.trimSettings.rearLeft));
    getConfigValue(EEPROM_ADDR_TRIM_REAR_RIGHT, &(audioConfig.trimSettings.rearRight));
    getConfigValue(EEPROM_ADDR_TRIM_CENTER, &(audioConfig.trimSettings.center));
    getConfigValue(EEPROM_ADDR_TRIM_SUBWOOFER, &(audioConfig.trimSettings.subwoofer));

    getConfigValue(EEPROM_ADDR_BASS, &(audioConfig.toneSettings.bass));
    getConfigValue(EEPROM_ADDR_TREBLE, &(audioConfig.toneSettings.treble));
    getConfigValue(EEPROM_ADDR_MID, &(audioConfig.toneSettings.mid));

    getConfigValue(EEPROM_ADDR_3DFX, &(audioConfig.is3DDisable));
    getConfigValue(EEPROM_ADDR_TONE, &(audioConfig.isToneDisable));

    // Apply default configurations to the PT2322.
    updateTrimLevels(&(audioConfig.trimSettings));
    updateToneLevels(&(audioConfig.toneSettings));

    setMute(audioConfig.isMute);
    setTone(audioConfig.isToneDisable);
    set3DAudio(audioConfig.is3DDisable);

    setMasterVolume(audioConfig.master);

    // Get current state of the input buttons.
    lastVolUp = digitalRead(PIN_VOL_UP);
    lastVolDown = digitalRead(PIN_VOL_DOWN);
    lastMute = digitalRead(PIN_MUTE);

    // Initialize button press detection variables.
    pressDelay = millis();
    autoInc = FALSE;
    autoDec = FALSE;
}

void loop() 
{
    // Reset button press detection timer at the beginning of the button press.
    if(((lastVolUp == HIGH) && (digitalRead(PIN_VOL_UP) == LOW)) || ((lastVolDown == HIGH) && (digitalRead(PIN_VOL_DOWN) == LOW)))
    {
        pressDelay = millis();
    }
    
    // Handle continues volume increment.
    if((digitalRead(PIN_VOL_UP) == LOW) && ((millis() - pressDelay) > BUTTON_PRESS_DELAY))
    {
        pressDelay = millis();
        if(audioConfig.master > PT2322_MASTER_VOLUME_MAX)
        {
            audioConfig.master = audioConfig.master - 1;
            setMasterVolume(audioConfig.master);
            sendControlValue(CNT_GET_MASTER, audioConfig.master);
            autoInc = TRUE;
        } 
    }

    // Handle continues volume decrement.
    if((digitalRead(PIN_VOL_DOWN) == LOW) && ((millis() - pressDelay) > BUTTON_PRESS_DELAY))
    {
        pressDelay = millis();
        if(audioConfig.master < PT2322_MASTER_VOLUME_MIN)
        {
            audioConfig.master = audioConfig.master + 1;
            setMasterVolume(audioConfig.master);
            sendControlValue(CNT_GET_MASTER, audioConfig.master);
            autoDec = TRUE;
        } 
    }
    
    // Check for Volume UP button event.
    if((lastVolUp == LOW) && (digitalRead(PIN_VOL_UP) == HIGH))
    {          
        // Avoid volume increment on button release after long press.
        if(autoInc)
        {
            autoInc = FALSE;
            EEPROM.update(EEPROM_ADDR_MASTER_VOLUME, audioConfig.master); 
        }
        else if(audioConfig.master > PT2322_MASTER_VOLUME_MAX)
        {
            audioConfig.master = audioConfig.master - 1;
            setMasterVolume(audioConfig.master);
            sendControlValue(CNT_GET_MASTER, audioConfig.master);
            EEPROM.update(EEPROM_ADDR_MASTER_VOLUME, audioConfig.master);
        }  

        delay(BUTTON_PRESS_DELAY);      
    }

    // Check for Volume DOWN button event.
    if((lastVolDown == LOW) && (digitalRead(PIN_VOL_DOWN) == HIGH))
    {
        // Avoid volume decrement on button release after long press.
        if(autoDec)
        {
            autoDec = FALSE;
            EEPROM.update(EEPROM_ADDR_MASTER_VOLUME, audioConfig.master); 
        }
        else if(audioConfig.master < PT2322_MASTER_VOLUME_MIN)
        {
            audioConfig.master = audioConfig.master + 1;
            setMasterVolume(audioConfig.master);
            sendControlValue(CNT_GET_MASTER, audioConfig.master);   
            EEPROM.update(EEPROM_ADDR_MASTER_VOLUME, audioConfig.master);         
        }   

        delay(BUTTON_PRESS_DELAY);     
    }
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

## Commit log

2022-10-21 Initial commit of source files and design files.
    [6ch-sound-fx-proc.kicad_pcb, 6ch-sound-fx-proc.kicad_sch, 6ch-sound-fx-proc.sch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]
2022-10-24 Update version information of the schematic and PCB design.
    [6ch-sound-fx-proc.kicad_pcb, 6ch-sound-fx-proc.kicad_sch, arduino-intf.kicad_sch]
2022-10-24 Add BOM file and readme.md file.
    [bom.ods]
2022-10-24 Add PDF version of the schematic.
2022-10-24 Add image of the prototype project and application screenshot.
2022-10-24 Update resolution of the assembled PCB image.
2022-10-24 Add board and application images to the readme.md file.
2022-10-24 Change BOM file name.
    [6ch-sound-fx-proc-bom.ods]
2022-10-24 Fix compilation issues with GCC 9.3.
    [main.c]
2022-10-24 Fix UI issues in serial connection path.
    [main.c]
2022-10-24 Add PCBWay project page URL.

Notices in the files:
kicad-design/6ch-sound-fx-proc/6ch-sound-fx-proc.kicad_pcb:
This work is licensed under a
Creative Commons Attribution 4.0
